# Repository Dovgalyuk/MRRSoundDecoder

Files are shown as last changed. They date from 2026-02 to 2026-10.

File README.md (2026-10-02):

# Maple RailRoad Sound Decoder

WiFi controller, sound decoder, and sound projects for model trains.

Project includes library for programming the sounds with set of state machines.

There are several ready-to-use sample sound projects.

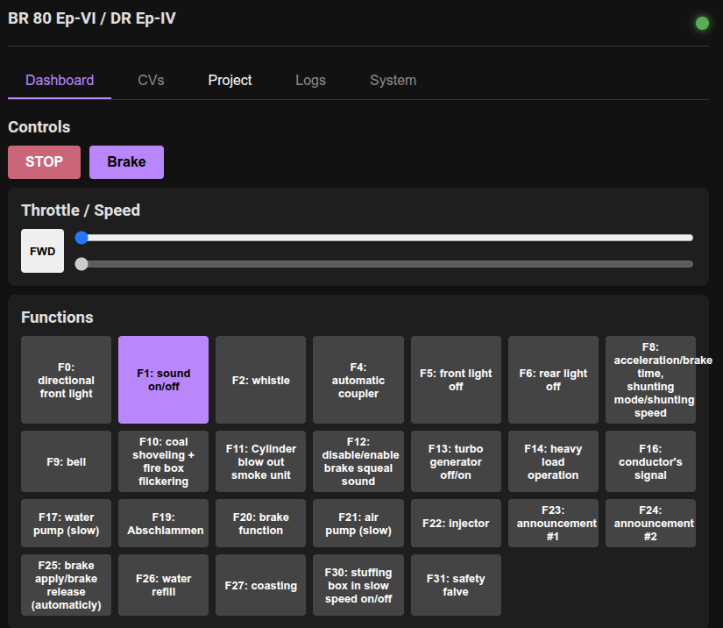
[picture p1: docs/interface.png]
Web interface for locomotive operation


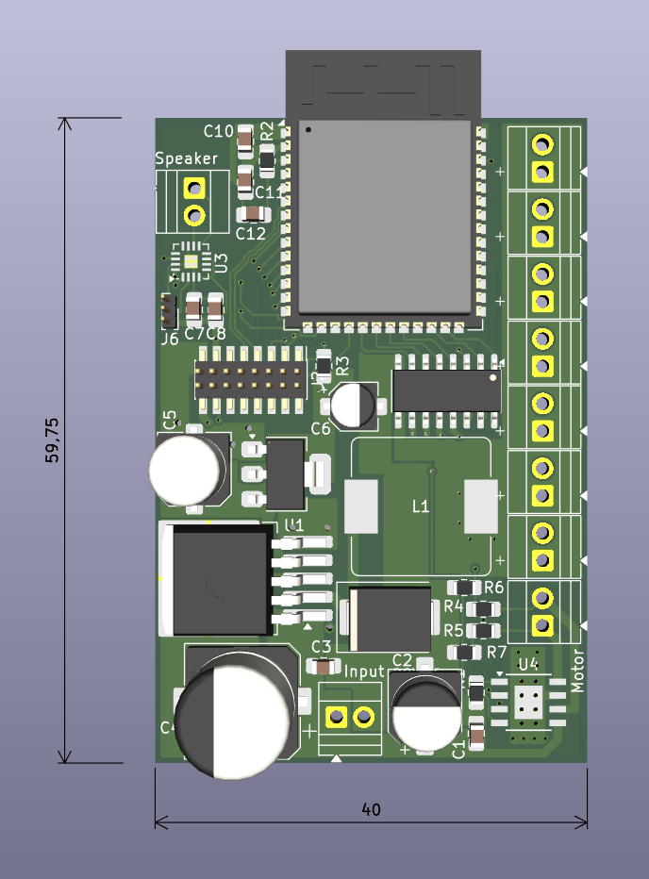
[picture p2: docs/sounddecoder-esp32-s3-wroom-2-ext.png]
Render of the PCB


# Project structure

* esp32 - firmwares for decoder and command station
* hardware - several versions of PCBs for manufacturing the decoder
* projects - ready-to-use sound projects for different locomotives
* compiler - compiler for the sound projects
* emulator - cab emulator for listening sounds with virtual locomotive control
* sample - dummy player which generates wav file by interpreting the sound project
* other directories include the source code of the firmware

# Bringing locomotive to life

* Get the hardware (order PCB, solder the components)
* Build firmware
  * Install ESP32 toolkit (esp idf)
  * Run esp32/decoder/build32M.sh (or other version)
* Upload esp32/decoder/build32M/esp32sounddecoder.bin into the ESP32 module
* Build selected sound project with compiler/compiler.py
* Upload built project through the web interface into the controller
* Install the controller into the locomotive

# Software features

Controller provides web interface that may be accessed through
WiFi (default address 192.168.4.1).

Sound module plays 8- or 16-bit sounds in 8 channels.

Output functions and sound schemes are programmed with
custom language. The scripts may include conditions,
loops, and finite state machines. These features
may be used for creating complex sound projects.

# Hardware

Controller is intended to be used with G-scale locomotives
with lithium batteries installed, but it may also be used
with track power (some power capacitors are probably needed).

Controller includes the following hardware components:
* ESP32 CPU with embedded WiFi module and flash memory
* Motor driver
* I2S audio power amplifier (MAX98357A)
* 7 programmable outputs
* BEMF for adjusting the motor speed (work in progress)

# Roadmap

* BEMF with new motor driver
* Support of logical input/outputs
* H0-compatible PCB

# Links

* Radio-controlled engines with sound
  - https://github.com/TheDIYGuy999/Rc_Engine_Sound_ESP32
* Cost effective DIY DCC Decoder for model railroad locomotives
  - https://github.com/gab-k/RP2040-Decoder
* NIMRS: open-source NIMRS-21Pin-Decoder, based on the ESP32-S3 microcontroller
  - https://github.com/CDFER/NIMRS-21Pin-Decoder
  - https://github.com/ProjectInitiative/NIMRS-Firmware

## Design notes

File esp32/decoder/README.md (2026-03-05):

# Prerequisites

Install ESP-IDF toolchain: https://docs.espressif.com/projects/esp-idf/en/stable/esp32/get-started/linux-macos-setup.html

Set environment variables: ```. {IDF PATH}/export.sh```

# Build

```
cd esp32

# choose target: esp32 or esp32s3
idf.py set-target esp32

idf.py build flash monitor
```

# Usage

Connect to WiFi train/12345678

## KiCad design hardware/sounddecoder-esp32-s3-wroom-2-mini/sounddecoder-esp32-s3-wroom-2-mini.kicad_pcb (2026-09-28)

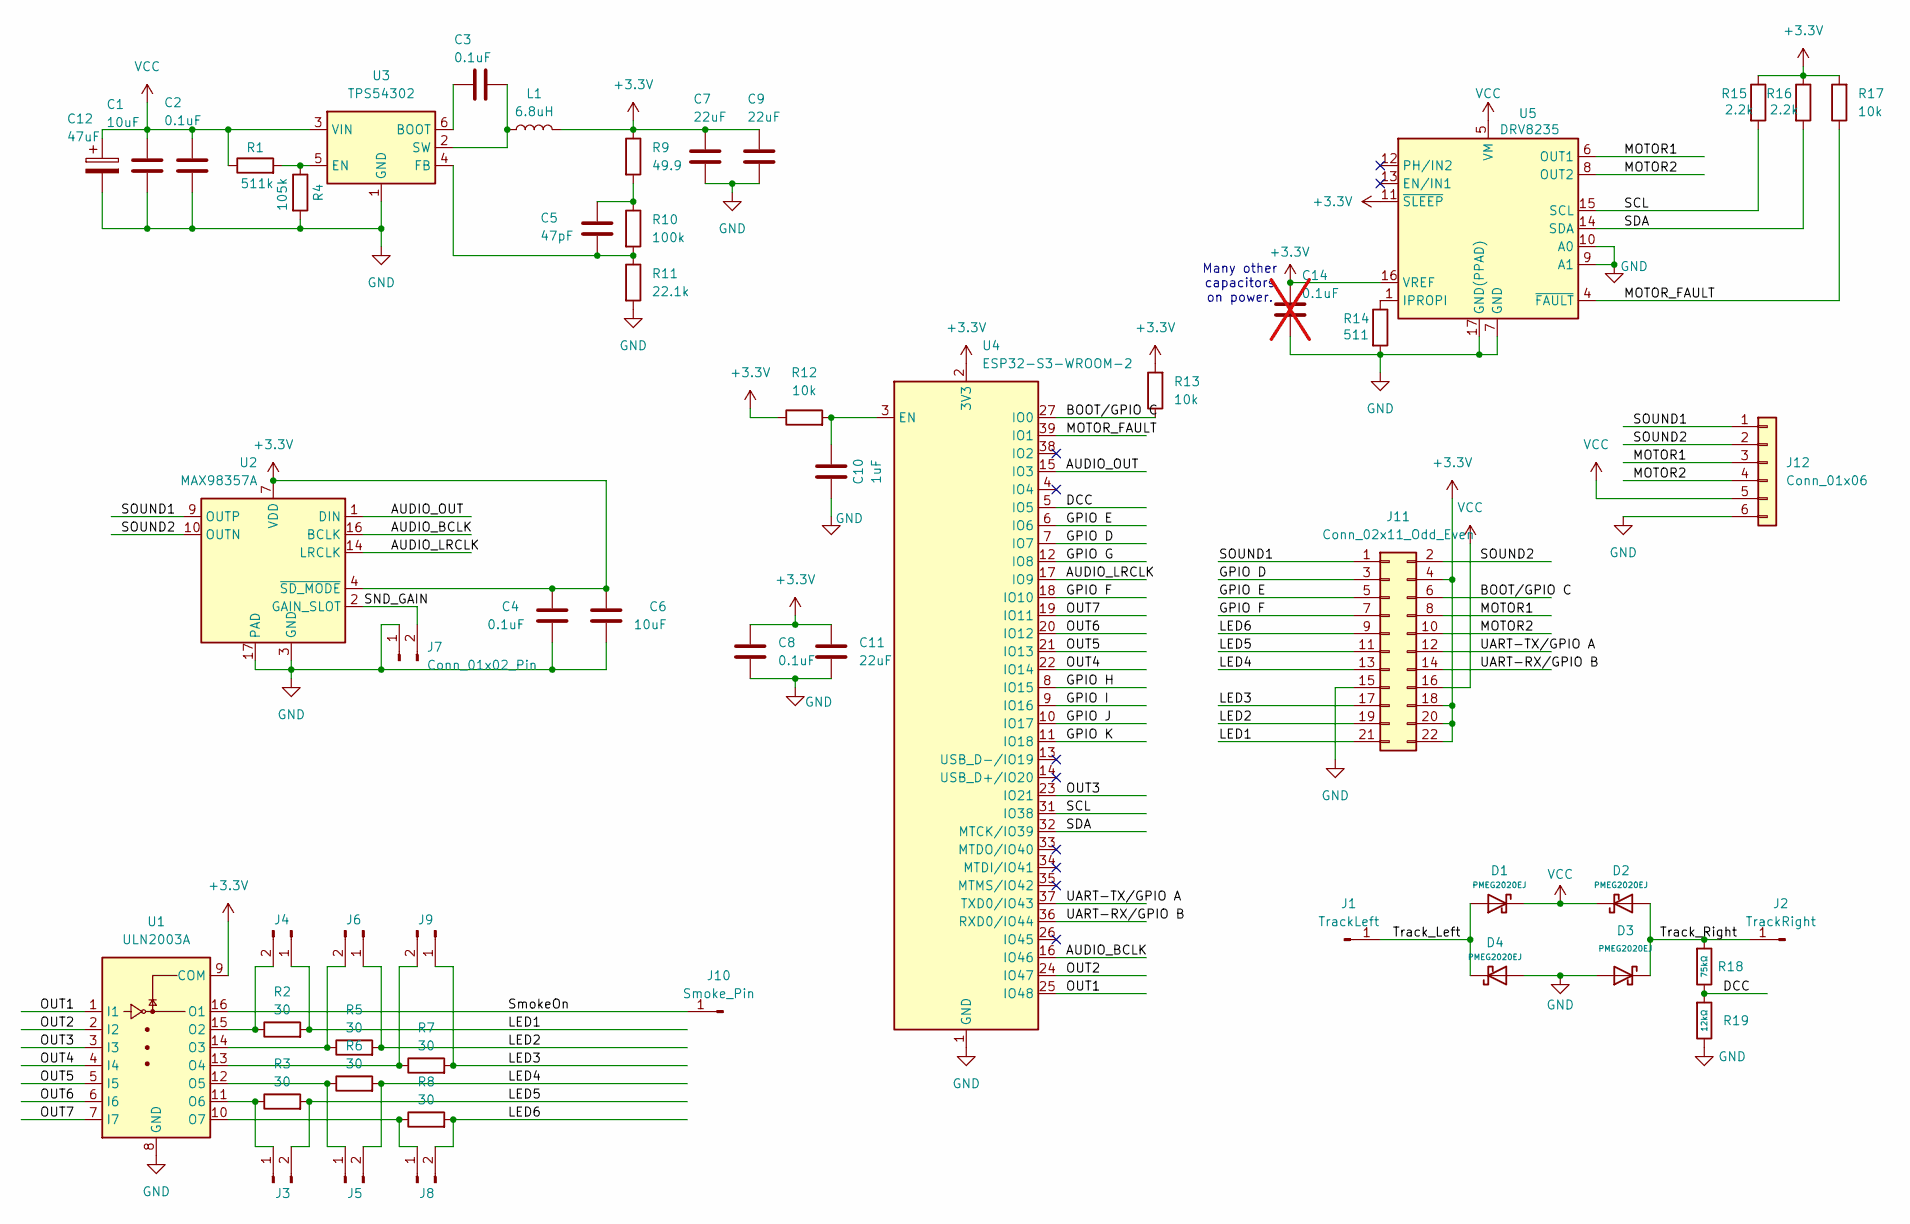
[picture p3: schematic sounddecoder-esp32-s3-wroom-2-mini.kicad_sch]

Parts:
C1, C6: 10uF; C_0603_1608Metric
C2, C3, C4, C8: 0.1uF; C_0603_1608Metric
C5: 47pF; C_0603_1608Metric
C7, C9, C11: 22uF; C_0603_1608Metric
C10: 1uF; C_0603_1608Metric
C12: 47uF; CP_Elec_6.3x5.4
C14: 0.1uF; C_0603_1608Metric; not fitted
D1, D2, D3, D4: PMEG2020EJ; D_SOD-323; Forward Voltage (Vf@If) 450mV@1.0A; Reverse Voltage (Vr) 20V; Part B5817WS; LCSC C7420329
J1: TrackLeft; TestPoint_THTPad_1.0x1.0mm_Drill0.5mm
J2: TrackRight; TestPoint_THTPad_1.0x1.0mm_Drill0.5mm
J3, J4, J5, J6, J7, J8, J9: Conn_01x02_Pin; SolderJumper-2_P1.3mm_Open_RoundedPad1.0x1.5mm
J10: Smoke_Pin; TestPoint_THTPad_1.0x1.0mm_Drill0.5mm
J11: Conn_02x11_Odd_Even; PinHeader_2x11_P2.00mm_Vertical
J12: Conn_01x06; PinHeader_1x06_P2.54mm_Vertical
L1: 6.8uH; L_Chilisin_BMRA00050530
R1: 511k; C_0603_1608Metric
R2, R3, R5, R6, R7, R8: 30; C_0603_1608Metric
R4: 105k; C_0603_1608Metric
R9: 49.9; C_0603_1608Metric
R10: 100k; C_0603_1608Metric
R11: 22.1k; C_0603_1608Metric
R12, R13, R17: 10k; C_0603_1608Metric
R14: 511; C_0603_1608Metric
R15, R16: 2.2k; C_0603_1608Metric
R18: 75kΩ; C_0603_1608Metric; Overload Voltage (Max) 50V; Tolerance ±1%; Part 0402WGF7502TCE; LCSC C25798
R19: 12kΩ; C_0603_1608Metric; Overload Voltage (Max) 50V; Tolerance ±1%; Part 0402WGF2002TCE; LCSC C25765
U1: ULN2003A; SO-16_3.9x9.9mm_P1.27mm
U2: MAX98357A; TQFN-16-1EP_3x3mm_P0.5mm_EP1.23x1.23mm
U3: TPS54302; SOT-23-6
U4: ESP32-S3-WROOM-2
U5: DRV8235; WQFN-16-1EP_3x3mm_P0.5mm_EP1.68x1.68mm_ThermalVias

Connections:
+3.3V: C4.1, C6.1, C7.1, C8.1, C9.1, C11.1, C14.1, J11.4, J11.18, J11.20, J11.22, L1.2, R9.1, R12.1, R13.2, R15.1, R16.1, R17.2, U1.9 (COM), U2.4 (~SD_MODE), U2.7 (VDD), U2.8 (VDD), U4.2 (3V3), U5.11 (~SLEEP), U5.16 (VREF)
/AUDIO_BCLK: U2.16 (BCLK), U4.16 (IO46)
/AUDIO_LRCLK: U2.14 (LRCLK), U4.17 (IO9)
/AUDIO_OUT: U2.1 (DIN), U4.15 (IO3)
/BOOT/GPIO C: J11.6, R13.1, U4.27 (IO0)
/DCC: R18.2, R19.1, U4.5 (IO5)
/GPIO D: J11.3, U4.7 (IO7)
/GPIO E: J11.5, U4.6 (IO6)
/GPIO F: J11.7, U4.18 (IO10)
/GPIO G: U4.12 (IO8)
/GPIO H: U4.8 (IO15)
/GPIO I: U4.9 (IO16)
/GPIO J: U4.10 (IO17)
/GPIO K: U4.11 (IO18)
/LED1: J4.1, J11.21, R2.2
/LED2: J6.1, J11.19, R5.2
/LED3: J9.1, J11.17, R7.2
/LED4: J5.2, J11.13, R6.2
/LED5: J3.2, J11.11, R3.2
/LED6: J8.2, J11.9, R8.2
/MOTOR1: J11.8, J12.3, U5.6 (OUT1)
/MOTOR2: J11.10, J12.4, U5.8 (OUT2)
/MOTOR_FAULT: R17.1, U4.39 (IO1), U5.4 (~FAULT)
/OUT1: U1.1 (I1), U4.25 (IO48)
/OUT2: U1.2 (I2), U4.24 (IO47)
/OUT3: U1.3 (I3), U4.23 (IO21)
/OUT4: U1.4 (I4), U4.22 (IO14)
/OUT5: U1.5 (I5), U4.21 (IO13)
/OUT6: U1.6 (I6), U4.20 (IO12)
/OUT7: U1.7 (I7), U4.19 (IO11)
/SCL: R15.2, U4.31 (IO38), U5.15 (SCL)
/SDA: R16.2, U4.32 (MTCK/IO39), U5.14 (SDA)
/SND_GAIN: J7.2, U2.2 (GAIN_SLOT)
/SOUND1: J11.1, J12.1, U2.9 (OUTP)
/SOUND2: J11.2, J12.2, U2.10 (OUTN)
/SmokeOn: J10.1, U1.16 (O1)
/Track_Left: D1.2, D4.1, J1.1
/Track_Right: D2.2, D3.1, J2.1, R18.1
/UART-RX/GPIO B: J11.14, U4.36 (RXD0/IO44)
/UART-TX/GPIO A: J11.12, U4.37 (TXD0/IO43)
GND: C1.2, C2.2, C4.2, C6.2, C7.2, C8.2, C9.2, C10.1, C11.2, C12.2, C14.2, D3.2, D4.2, J7.1, J11.15, J12.6, R4.2, R11.2, R14.2, R19.2, U1.8 (GND), U2.3 (GND), U2.11 (GND), U2.15 (GND), U2.17 (PAD), U3.1 (GND), U4.1 (GND), U4.40 (GND), U4.41 (GND), U5.7 (GND), U5.9 (A1), U5.10 (A0), U5.17 (GND(PPAD))
unnamed: C5.1, R9.2, R10.1
unnamed: J3.1, R3.1, U1.11 (O6)
unnamed: J4.2, R2.1, U1.15 (O2)
unnamed: J5.1, R6.1, U1.12 (O5)
unnamed: J6.2, R5.1, U1.14 (O3)
unnamed: J8.1, R8.1, U1.10 (O7)
unnamed: J9.2, R7.1, U1.13 (O4)
unnamed: C3.1, U3.6 (BOOT)
unnamed: R1.2, R4.1, U3.5 (EN)
unnamed: C5.2, R10.2, R11.1, U3.4 (FB)
unnamed: C3.2, L1.1, U3.2 (SW)
unnamed: C10.2, R12.2, U4.3 (EN)
unnamed: R14.1, U5.1 (IPROPI)
VCC: C1.1, C2.1, C12.1, D1.1, D2.1, J11.16, J12.5, R1.1, U3.3 (VIN), U5.5 (VM)

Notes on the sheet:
Many other capacitors on power.

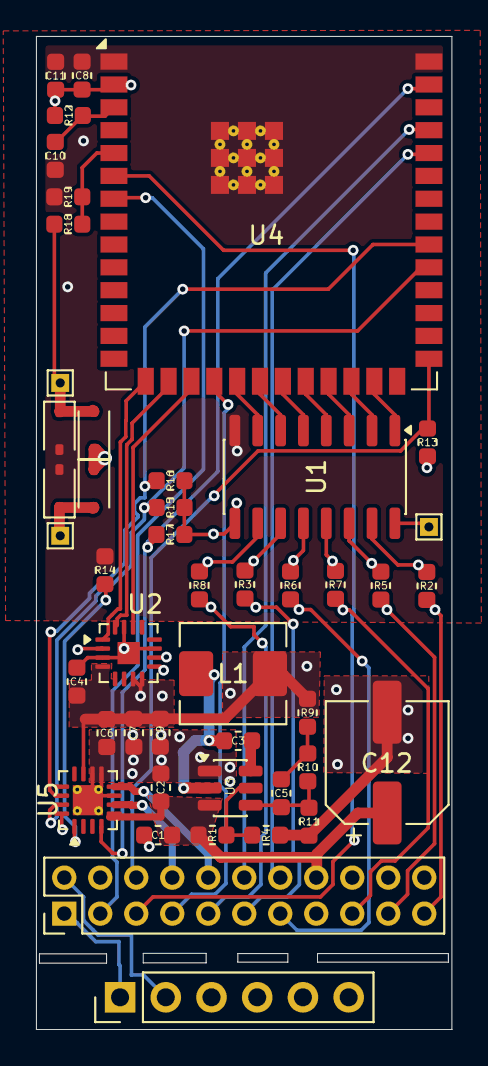
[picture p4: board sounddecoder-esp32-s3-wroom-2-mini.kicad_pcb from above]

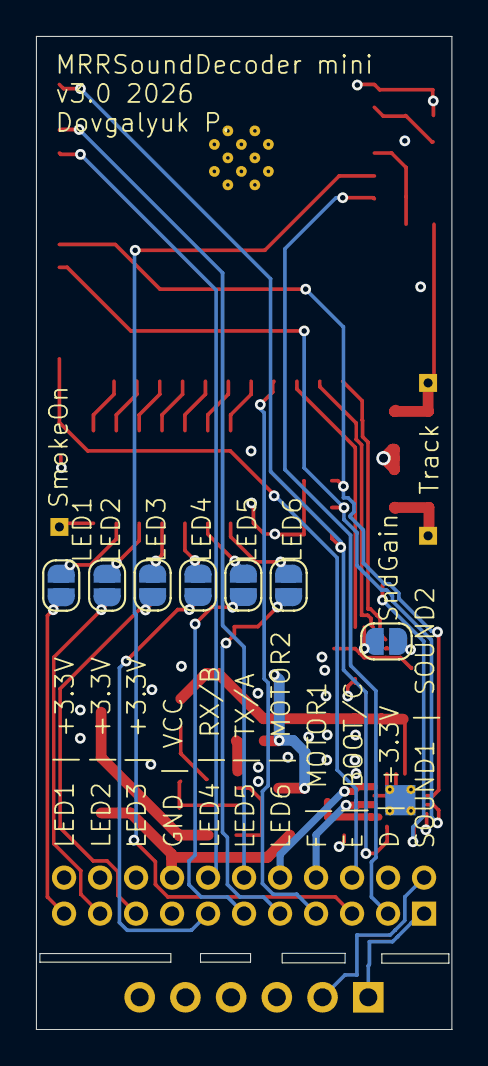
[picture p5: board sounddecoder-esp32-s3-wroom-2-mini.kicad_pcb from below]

Board: 4 copper layers, 23.1 x 55.2 mm, 53 parts (7 on the bottom side), 50 nets.

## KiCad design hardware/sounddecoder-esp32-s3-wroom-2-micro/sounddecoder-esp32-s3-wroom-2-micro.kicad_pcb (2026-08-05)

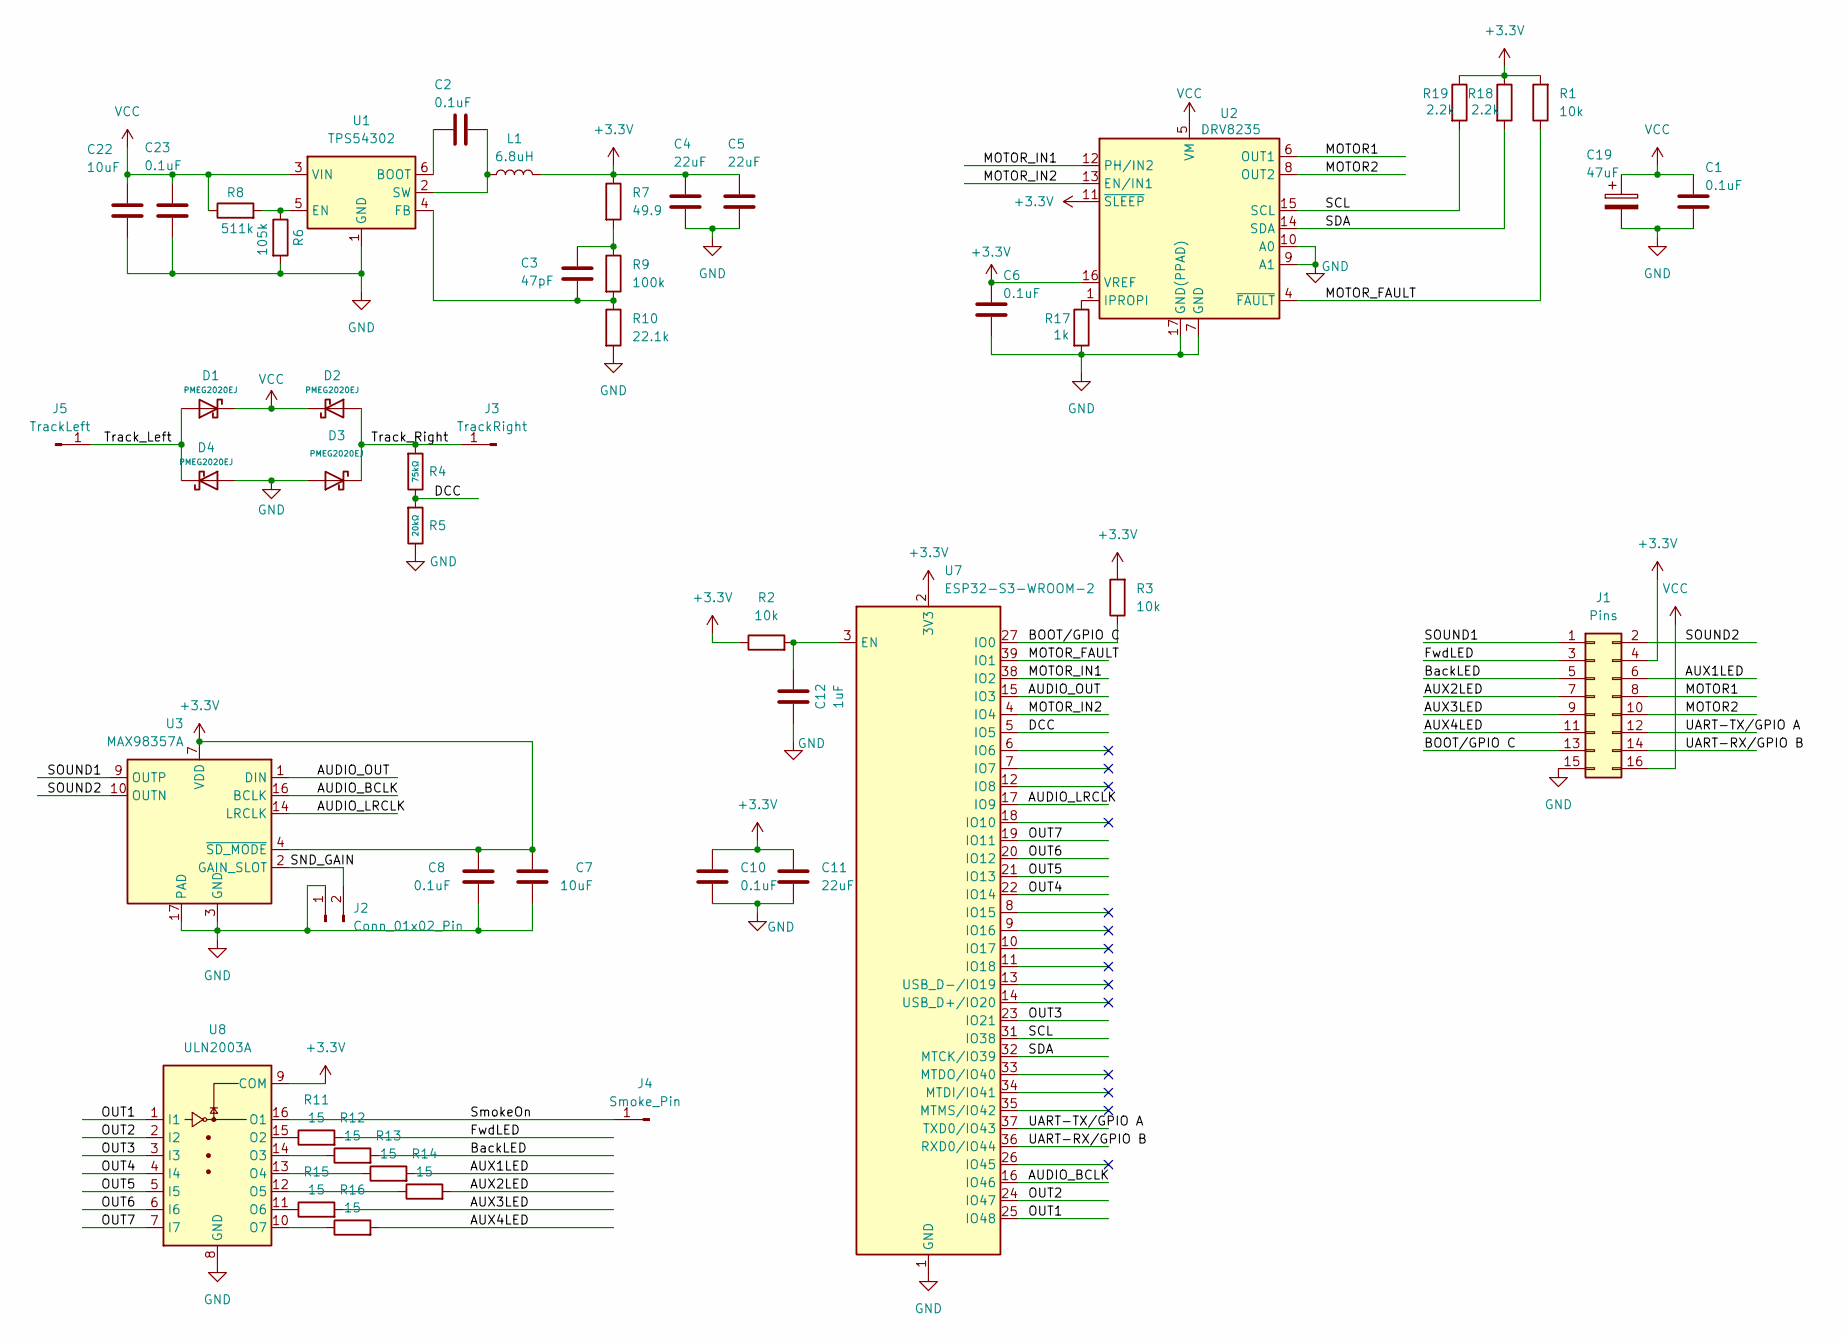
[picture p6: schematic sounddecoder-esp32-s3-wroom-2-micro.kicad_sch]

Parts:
C1, C2, C6, C8, C10, C23: 0.1uF; C_0603_1608Metric
C3: 47pF; C_0603_1608Metric
C4, C5, C11: 22uF; C_0603_1608Metric
C7, C22: 10uF; C_0603_1608Metric
C12: 1uF; C_0603_1608Metric
C19: 47uF; CP_Elec_6.3x5.4
D1, D2, D3, D4: PMEG2020EJ; D_SOD-323; Forward Voltage (Vf@If) 450mV@1.0A; Reverse Voltage (Vr) 20V; Part B5817WS; LCSC C7420329
J1: Pins; PinHeader_2x08_P2.00mm_Vertical
J2: Conn_01x02_Pin; SolderJumper-2_P1.3mm_Open_RoundedPad1.0x1.5mm
J3: TrackRight; TestPoint_THTPad_1.0x1.0mm_Drill0.5mm
J4: Smoke_Pin; TestPoint_THTPad_1.0x1.0mm_Drill0.5mm
J5: TrackLeft; TestPoint_THTPad_1.0x1.0mm_Drill0.5mm
L1: 6.8uH; L_Chilisin_BMRA00050530
R1, R2, R3: 10k; C_0603_1608Metric
R4: 75kΩ; C_0603_1608Metric; Overload Voltage (Max) 50V; Tolerance ±1%; Part 0402WGF7502TCE; LCSC C25798
R5: 20kΩ; C_0603_1608Metric; Overload Voltage (Max) 50V; Tolerance ±1%; Part 0402WGF2002TCE; LCSC C25765
R6: 105k; C_0603_1608Metric
R7: 49.9; C_0603_1608Metric
R8: 511k; C_0603_1608Metric
R9: 100k; C_0603_1608Metric
R10: 22.1k; C_0603_1608Metric
R11, R12, R13, R14, R15, R16: 15; C_0603_1608Metric
R17: 1k; C_0603_1608Metric
R18, R19: 2.2k; C_0603_1608Metric
U1: TPS54302; SOT-23-6
U2: DRV8235; WQFN-16-1EP_3x3mm_P0.5mm_EP1.68x1.68mm_ThermalVias
U3: MAX98357A; TQFN-16-1EP_3x3mm_P0.5mm_EP1.23x1.23mm
U7: ESP32-S3-WROOM-2
U8: ULN2003A; SO-16_3.9x9.9mm_P1.27mm

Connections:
+3.3V: C4.1, C5.1, C6.1, C7.1, C8.1, C10.1, C11.1, J1.4, L1.2, R1.2, R2.1, R3.2, R7.1, R18.1, R19.1, U2.11 (~SLEEP), U2.16 (VREF), U3.4 (~SD_MODE), U3.7 (VDD), U3.8 (VDD), U7.2 (3V3), U8.9 (COM)
/AUDIO_BCLK: U3.16 (BCLK), U7.16 (IO46)
/AUDIO_LRCLK: U3.14 (LRCLK), U7.17 (IO9)
/AUDIO_OUT: U3.1 (DIN), U7.15 (IO3)
/AUX1LED: J1.6, R13.2
/AUX2LED: J1.7, R14.2
/AUX3LED: J1.9, R15.2
/AUX4LED: J1.11, R16.2
/BOOT/GPIO C: J1.13, R3.1, U7.27 (IO0)
/BackLED: J1.5, R12.2
/DCC: R4.2, R5.1, U7.5 (IO5)
/FwdLED: J1.3, R11.2
/MOTOR1: J1.8, U2.6 (OUT1)
/MOTOR2: J1.10, U2.8 (OUT2)
/MOTOR_FAULT: R1.1, U2.4 (~FAULT), U7.39 (IO1)
/MOTOR_IN1: U2.12 (PH/IN2), U7.38 (IO2)
/MOTOR_IN2: U2.13 (EN/IN1), U7.4 (IO4)
/OUT1: U7.25 (IO48), U8.1 (I1)
/OUT2: U7.24 (IO47), U8.2 (I2)
/OUT3: U7.23 (IO21), U8.3 (I3)
/OUT4: U7.22 (IO14), U8.4 (I4)
/OUT5: U7.21 (IO13), U8.5 (I5)
/OUT6: U7.20 (IO12), U8.6 (I6)
/OUT7: U7.19 (IO11), U8.7 (I7)
/SCL: R19.2, U2.15 (SCL), U7.31 (IO38)
/SDA: R18.2, U2.14 (SDA), U7.32 (MTCK/IO39)
/SND_GAIN: J2.2, U3.2 (GAIN_SLOT)
/SOUND1: J1.1, U3.9 (OUTP)
/SOUND2: J1.2, U3.10 (OUTN)
/SmokeOn: J4.1, U8.16 (O1)
/Track_Left: D1.2, D4.1, J5.1
/Track_Right: D2.2, D3.1, J3.1, R4.1
/UART-RX/GPIO B: J1.14, U7.36 (RXD0/IO44)
/UART-TX/GPIO A: J1.12, U7.37 (TXD0/IO43)
GND: C1.2, C4.2, C5.2, C6.2, C7.2, C8.2, C10.2, C11.2, C12.1, C19.2, C22.2, C23.2, D3.2, D4.2, J1.15, J2.1, R5.2, R6.2, R10.2, R17.2, U1.1 (GND), U2.7 (GND), U2.9 (A1), U2.10 (A0), U2.17 (GND(PPAD)), U3.3 (GND), U3.11 (GND), U3.15 (GND), U3.17 (PAD), U7.1 (GND), U7.40 (GND), U7.41 (GND), U8.8 (GND)
unnamed: C3.1, R7.2, R9.1
unnamed: C2.1, U1.6 (BOOT)
unnamed: R6.1, R8.2, U1.5 (EN)
unnamed: C3.2, R9.2, R10.1, U1.4 (FB)
unnamed: C2.2, L1.1, U1.2 (SW)
unnamed: R17.1, U2.1 (IPROPI)
unnamed: C12.2, R2.2, U7.3 (EN)
unnamed: R11.1, U8.15 (O2)
unnamed: R12.1, U8.14 (O3)
unnamed: R13.1, U8.13 (O4)
unnamed: R14.1, U8.12 (O5)
unnamed: R15.1, U8.11 (O6)
unnamed: R16.1, U8.10 (O7)
VCC: C1.1, C19.1, C22.1, C23.1, D1.1, D2.1, J1.16, R8.1, U1.3 (VIN), U2.5 (VM)

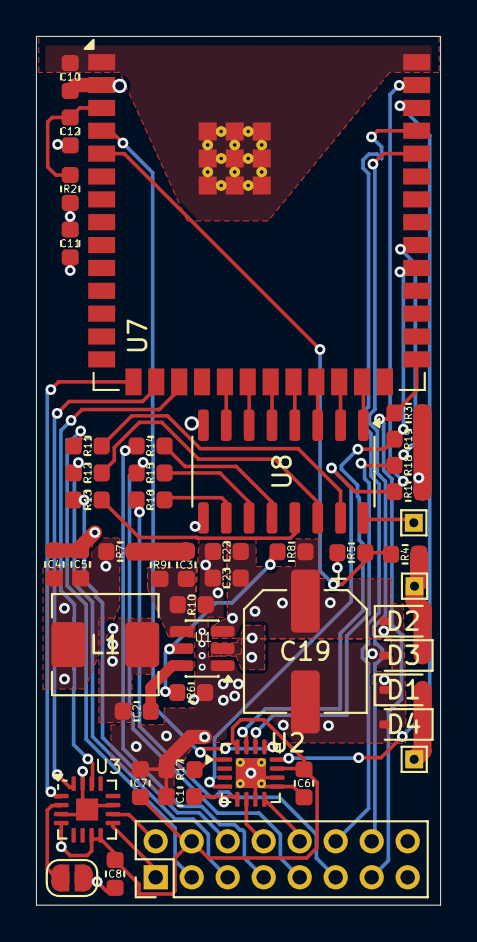
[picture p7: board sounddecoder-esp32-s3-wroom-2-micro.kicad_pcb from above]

Board: 4 copper layers, 22.5 x 48.3 mm, 48 parts (0 on the bottom side), 49 nets.

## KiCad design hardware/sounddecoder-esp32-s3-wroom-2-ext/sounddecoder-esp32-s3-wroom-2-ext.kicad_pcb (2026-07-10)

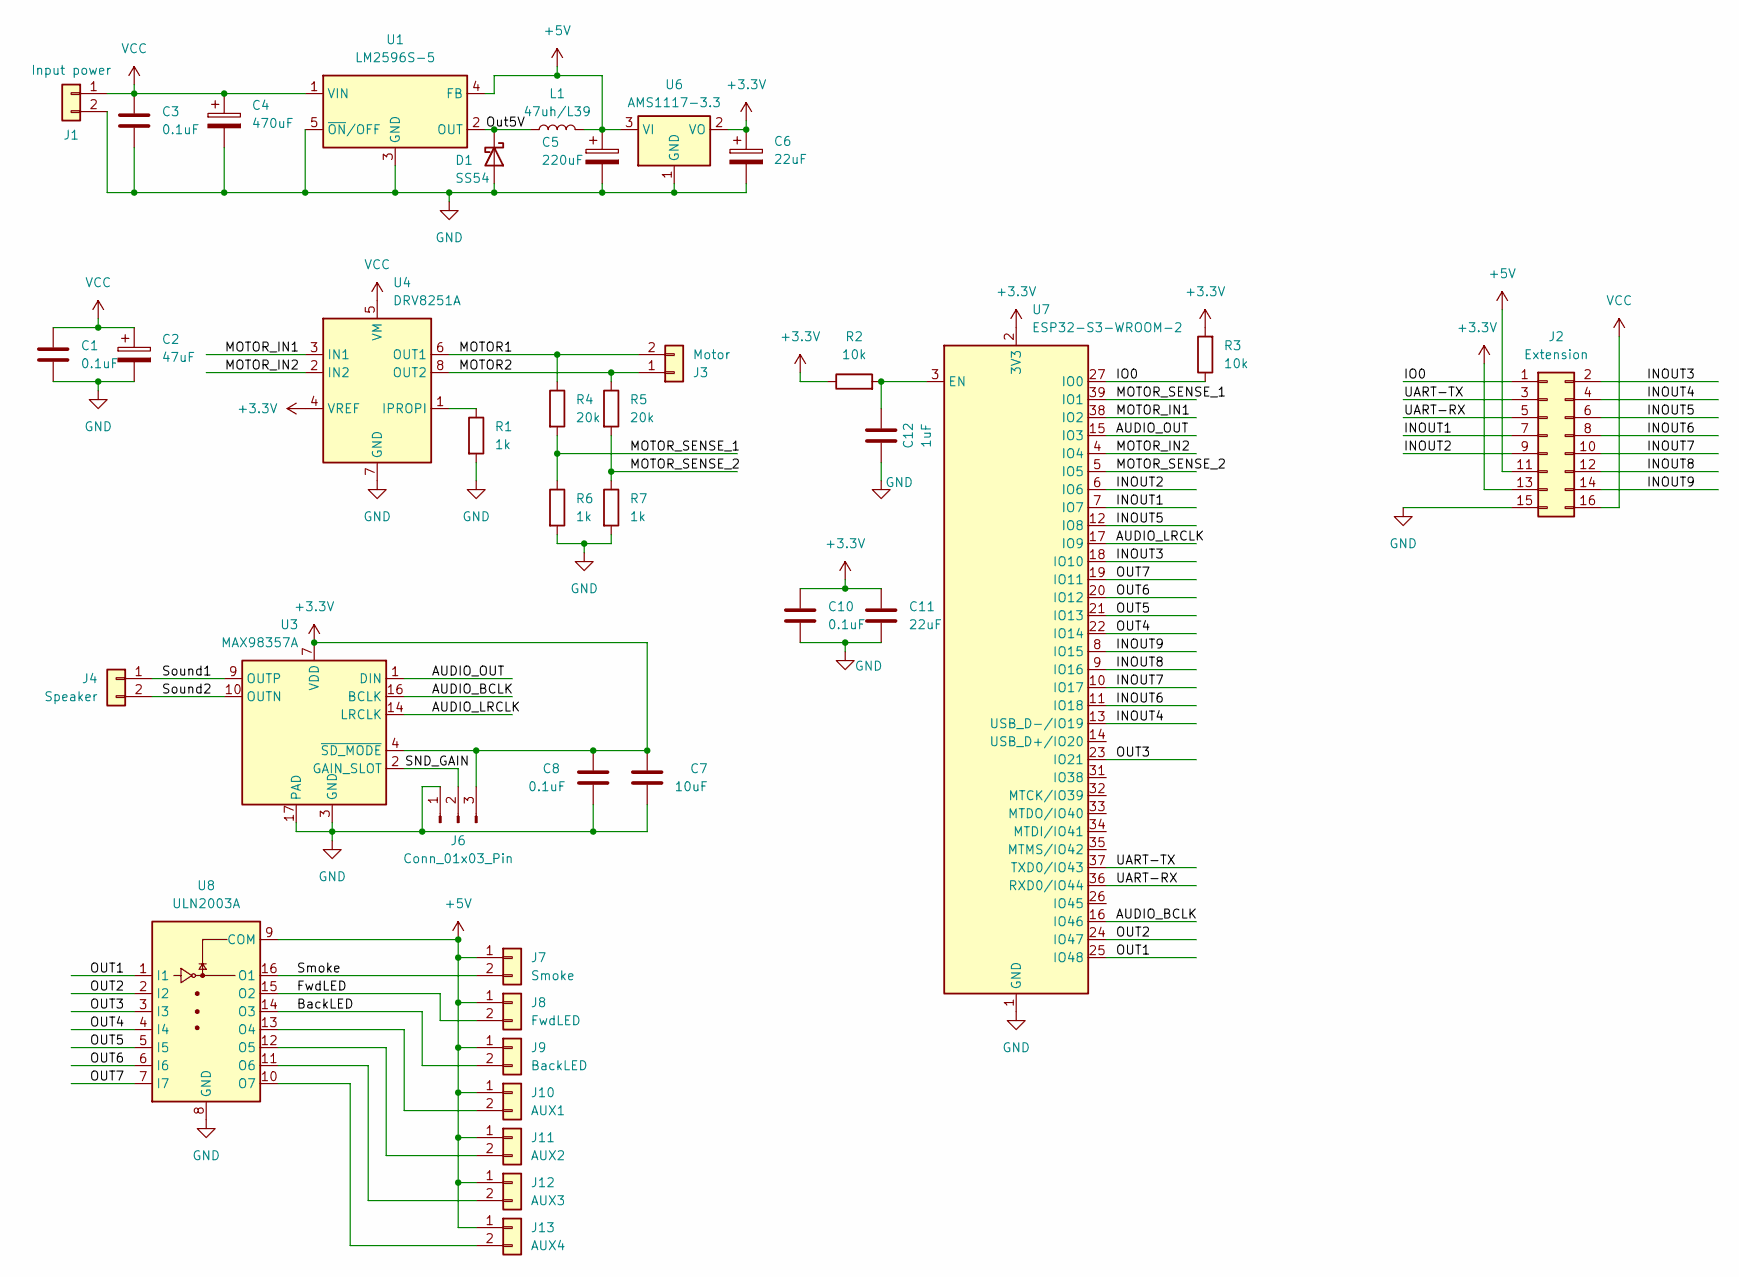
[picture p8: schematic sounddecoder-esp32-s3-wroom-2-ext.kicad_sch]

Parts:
C1, C3, C8, C10: 0.1uF; C_0805_2012Metric_Pad1.18x1.45mm_HandSolder
C2: 47uF; CP_Elec_6.3x5.4
C4: 470uF; CP_Elec_10x10.5
C5: 220uF; C_Elec_6.3x7.7
C6: 22uF; CP_Elec_4x5.4
C7: 10uF; C_0805_2012Metric_Pad1.18x1.45mm_HandSolder
C11: 22uF; C_0805_2012Metric_Pad1.18x1.45mm_HandSolder
C12: 1uF; C_0805_2012Metric_Pad1.18x1.45mm_HandSolder
D1: SS54; D_SMC
J1: Input power; TerminalBlock_Xinya_XY308-2.54-2P_1x02_P2.54mm_Horizontal
J2: Extension; PinHeader_2x08_P1.27mm_Vertical_SMD
J3: Motor; TerminalBlock_Xinya_XY308-2.54-2P_1x02_P2.54mm_Horizontal
J4: Speaker; TerminalBlock_Xinya_XY308-2.54-2P_1x02_P2.54mm_Horizontal
J6: Conn_01x03_Pin; PinHeader_1x03_P1.00mm_Vertical
J7: Smoke; TerminalBlock_Xinya_XY308-2.54-2P_1x02_P2.54mm_Horizontal
J8: FwdLED; TerminalBlock_Xinya_XY308-2.54-2P_1x02_P2.54mm_Horizontal
J9: BackLED; TerminalBlock_Xinya_XY308-2.54-2P_1x02_P2.54mm_Horizontal
J10: AUX1; TerminalBlock_Xinya_XY308-2.54-2P_1x02_P2.54mm_Horizontal
J11: AUX2; TerminalBlock_Xinya_XY308-2.54-2P_1x02_P2.54mm_Horizontal
J12: AUX3; TerminalBlock_Xinya_XY308-2.54-2P_1x02_P2.54mm_Horizontal
J13: AUX4; TerminalBlock_Xinya_XY308-2.54-2P_1x02_P2.54mm_Horizontal
L1: 47uh/L39; L_Bourns_SRP1245A
R1, R6, R7: 1k; R_0805_2012Metric_Pad1.20x1.40mm_HandSolder
R2, R3: 10k; R_0805_2012Metric_Pad1.20x1.40mm_HandSolder
R4, R5: 20k; R_0805_2012Metric_Pad1.20x1.40mm_HandSolder
U1: LM2596S-5; TO-263-5_TabPin3
U3: MAX98357A; TQFN-16-1EP_3x3mm_P0.5mm_EP1.23x1.23mm
U4: DRV8251A; Texas_HSOP-8-1EP_3.9x4.9mm_P1.27mm_ThermalVias
U6: AMS1117-3.3; SOT-223-3_TabPin2
U7: ESP32-S3-WROOM-2
U8: ULN2003A; SO-16_3.9x9.9mm_P1.27mm

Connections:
+3.3V: C6.1, C7.1, C8.1, C10.1, C11.1, J2.13, J6.3, R2.1, R3.2, U3.4 (~SD_MODE), U3.7 (VDD), U3.8 (VDD), U4.4 (VREF), U6.2 (VO), U7.2 (3V3)
+5V: C5.1, J2.11, J7.1, J8.1, J9.1, J10.1, J11.1, J12.1, J13.1, L1.2, U1.4 (FB), U6.3 (VI), U8.9 (COM)
/AUDIO_BCLK: U3.16 (BCLK), U7.16 (IO46)
/AUDIO_LRCLK: U3.14 (LRCLK), U7.17 (IO9)
/AUDIO_OUT: U3.1 (DIN), U7.15 (IO3)
/BackLED: J9.2, U8.14 (O3)
/FwdLED: J8.2, U8.15 (O2)
/INOUT1: J2.7, U7.7 (IO7)
/INOUT2: J2.9, U7.6 (IO6)
/INOUT3: J2.2, U7.18 (IO10)
/INOUT4: J2.4, U7.13 (USB_D-/IO19)
/INOUT5: J2.6, U7.12 (IO8)
/INOUT6: J2.8, U7.11 (IO18)
/INOUT7: J2.10, U7.10 (IO17)
/INOUT8: J2.12, U7.9 (IO16)
/INOUT9: J2.14, U7.8 (IO15)
/IO0: J2.1, R3.1, U7.27 (IO0)
/MOTOR1: J3.2, R4.1, U4.6 (OUT1)
/MOTOR2: J3.1, R5.1, U4.8 (OUT2)
/MOTOR_IN1: U4.3 (IN1), U7.38 (IO2)
/MOTOR_IN2: U4.2 (IN2), U7.4 (IO4)
/MOTOR_SENSE_1: R4.2, R6.1, U7.39 (IO1)
/MOTOR_SENSE_2: R5.2, R7.1, U7.5 (IO5)
/OUT1: U7.25 (IO48), U8.1 (I1)
/OUT2: U7.24 (IO47), U8.2 (I2)
/OUT3: U7.23 (IO21), U8.3 (I3)
/OUT4: U7.22 (IO14), U8.4 (I4)
/OUT5: U7.21 (IO13), U8.5 (I5)
/OUT6: U7.20 (IO12), U8.6 (I6)
/OUT7: U7.19 (IO11), U8.7 (I7)
/Out5V: D1.1 (K), L1.1, U1.2 (OUT)
/SND_GAIN: J6.2, U3.2 (GAIN_SLOT)
/Smoke: J7.2, U8.16 (O1)
/Sound1: J4.1, U3.9 (OUTP)
/Sound2: J4.2, U3.10 (OUTN)
/UART-RX: J2.5, U7.36 (RXD0/IO44)
/UART-TX: J2.3, U7.37 (TXD0/IO43)
GND: C1.2, C2.2, C3.2, C4.2, C5.2, C6.2, C7.2, C8.2, C10.2, C11.2, C12.1, D1.2 (A), J1.2, J2.15, J6.1, R1.2, R6.2, R7.2, U1.3 (GND), U1.5 (~ON/OFF), U3.3 (GND), U3.11 (GND), U3.15 (GND), U3.17 (PAD), U4.7 (GND), U4.9 (GND), U6.1 (GND), U7.1 (GND), U7.40 (GND), U7.41 (GND), U8.8 (GND)
unnamed: J10.2, U8.13 (O4)
unnamed: J11.2, U8.12 (O5)
unnamed: J12.2, U8.11 (O6)
unnamed: J13.2, U8.10 (O7)
unnamed: R1.1, U4.1 (IPROPI)
unnamed: C12.2, R2.2, U7.3 (EN)
VCC: C1.1, C2.1, C3.1, C4.1, J1.1, J2.16, U1.1 (VIN), U4.5 (VM)

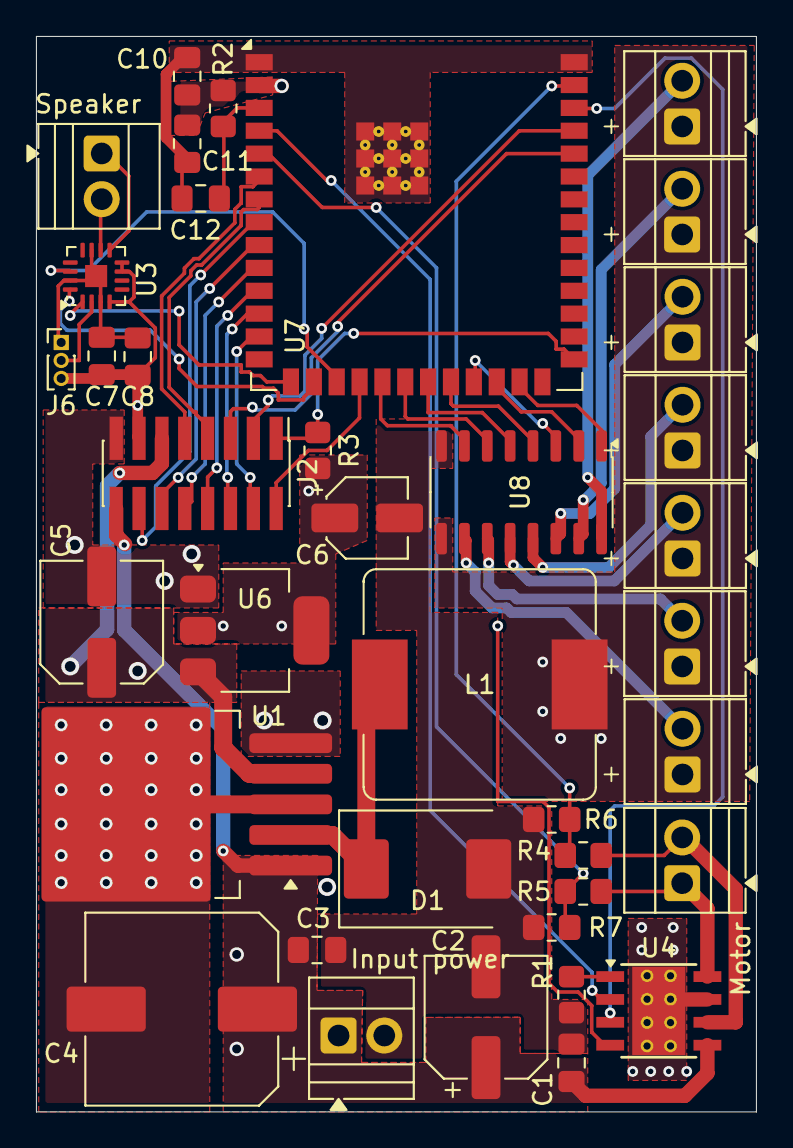
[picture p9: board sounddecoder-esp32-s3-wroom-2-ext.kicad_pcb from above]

Board: 4 copper layers, 40.0 x 59.8 mm, 38 parts (0 on the bottom side), 45 nets.

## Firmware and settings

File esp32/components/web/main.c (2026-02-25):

/* Async Request Handlers HTTP Server Example

   This example code is in the Public Domain (or CC0 licensed, at your option.)

   Unless required by applicable law or agreed to in writing, this
   software is distributed on an "AS IS" BASIS, WITHOUT WARRANTIES OR
   CONDITIONS OF ANY KIND, either express or implied.
*/
#include "freertos/FreeRTOS.h"
#include "freertos/semphr.h"
#include <esp_event.h>
#include <esp_log.h>
#include <esp_system.h>
#include <sys/param.h>
#include <esp_http_server.h>

/* An example that demonstrates multiple
   long running http requests running in parallel.

   In this example, multiple long http request can run at
   the same time. (uri: /long)

   While these long requests are running, the server can still
   respond to other incoming synchronous requests. (uri: /quick)
 */

#define ASYNC_WORKER_TASK_PRIORITY      5

static const char *TAG = "http";

// Async requests are queued here while they wait to
// be processed by the workers
static QueueHandle_t request_queue;

// Track the number of free workers at any given time
static SemaphoreHandle_t worker_ready_count;

// Each worker has its own thread
static TaskHandle_t worker_handles[CONFIG_HTTP_MAX_ASYNC_REQUESTS];

typedef esp_err_t (*httpd_req_handler_t)(httpd_req_t *req);

typedef struct {
    httpd_req_t* req;
    httpd_req_handler_t handler;
} httpd_async_req_t;

// queue an HTTP req to the worker queue
static esp_err_t queue_request(httpd_req_t *req, httpd_req_handler_t handler)
{
    // must create a copy of the request that we own
    httpd_req_t* copy = NULL;
    esp_err_t err = httpd_req_async_handler_begin(req, &copy);
    if (err != ESP_OK) {
        return err;
    }

    httpd_async_req_t async_req = {
        .req = copy,
        .handler = handler,
    };

    // How should we handle resource exhaustion?
    // In this example, we immediately respond with an
    // http error if no workers are available.
    int ticks = 0;

    // counting semaphore: if success, we know 1 or
    // more asyncReqTaskWorkers are available.
    if (xSemaphoreTake(worker_ready_count, ticks) == false) {
        ESP_LOGE(TAG, "No workers are available");
        httpd_req_async_handler_complete(copy); // cleanup
        return ESP_FAIL;
    }

    // Since worker_ready_count > 0 the queue should already have space.
    // But lets wait up to 100ms just to be safe.
    if (xQueueSend(request_queue, &async_req, pdMS_TO_TICKS(100)) == false) {
        ESP_LOGE(TAG, "worker queue is full");
        httpd_req_async_handler_complete(copy); // cleanup
        return ESP_FAIL;
    }

    return ESP_OK;
}

/* handle long request (on async thread) */
static esp_err_t long_async(httpd_req_t *req)
{
    char*  buf;
    size_t buf_len;

    /* Get URI */
    ESP_LOGI(TAG, "Request URI: %s", req->uri);

    /* Get header value string length and allocate memory for length + 1,
     * extra byte for null termination */
    buf_len = httpd_req_get_hdr_value_len(req, "Host") + 1;
    if (buf_len > 1) {
        buf = malloc(buf_len);
        if (buf == NULL) {
            ESP_LOGE(TAG, "Failed to allocate memory for headers");
            return ESP_FAIL;
        }
        /* Copy null terminated value string into buffer */
        if (httpd_req_get_hdr_value_str(req, "Host", buf, buf_len) == ESP_OK) {
            ESP_LOGI(TAG, "Found header => Host: %s", buf);
        }
        free(buf);
    }
    /* Get query string length and allocate memory for length + 1,
     * extra byte for null termination */
    buf_len = httpd_req_get_url_query_len(req) + 1;
    if (buf_len > 1) {
        buf = malloc(buf_len);
        if (buf == NULL) {
            ESP_LOGE(TAG, "Failed to allocate memory for query string");
            return ESP_FAIL;
        }
        /* Copy null terminated query string into buffer */
        if (httpd_req_get_url_query_str(req, buf, buf_len) == ESP_OK) {
            ESP_LOGI(TAG, "Found query string => %s", buf);
        }
        free(buf);
    }

    // track the number of long requests
    static uint8_t req_count = 0;
    req_count++;

    // send a request count
    char s[100];
    snprintf(s, sizeof(s), "<div>req: %u</div>\n", req_count);
    esp_err_t err = httpd_resp_sendstr_chunk(req, s);
    if (err != ESP_OK) {
        ESP_LOGE(TAG, "Failed to send string chunk: %s", esp_err_to_name(err));
        return err;
    }

    // then every second, send a "tick"
    for (int i = 0; i < 60; i++) {

        // This delay makes this a "long running task".
        // In a real application, this may be a long calculation,
        // or some IO dependent code for instance.
        vTaskDelay(pdMS_TO_TICKS(1000));

        // send a tick
        snprintf(s, sizeof(s), "<div>%u</div>\n", i);
        err = httpd_resp_sendstr_chunk(req, s);
        if (err != ESP_OK) {
            ESP_LOGE(TAG, "Failed to send string chunk: %s", esp_err_to_name(err));
            return err;
        }
    }

    // send "complete"
    err = httpd_resp_sendstr_chunk(req, NULL);
    if (err != ESP_OK) {
        ESP_LOGE(TAG, "Failed to send string chunk: %s", esp_err_to_name(err));
        return err;
    }

    return ESP_OK;
}

// each worker thread loops forever, processing requests
static void worker_task(void *p)
{
    ESP_LOGI(TAG, "starting async req task worker");

    while (true) {

        // counting semaphore - this signals that a worker
        // is ready to accept work
        xSemaphoreGive(worker_ready_count);

        // wait for a request
        httpd_async_req_t async_req;
        if (xQueueReceive(request_queue, &async_req, portMAX_DELAY)) {

            ESP_LOGI(TAG, "invoking %s", async_req.req->uri);

            // call the handler
            async_req.handler(async_req.req);

            // Inform the server that it can purge the socket used for
            // this request, if needed.
            if (httpd_req_async_handler_complete(async_req.req) != ESP_OK) {
                ESP_LOGE(TAG, "failed to complete async req");
            }
        }
    }

    ESP_LOGW(TAG, "worker stopped");
    vTaskDelete(NULL);
}

// start worker threads
static void start_workers(void)
{

    // counting semaphore keeps track of available workers
    worker_ready_count = xSemaphoreCreateCounting(
        CONFIG_HTTP_MAX_ASYNC_REQUESTS,  // Max Count
        0); // Initial Count
    if (worker_ready_count == NULL) {
        ESP_LOGE(TAG, "Failed to create workers counting Semaphore");
        return;
    }

    // create queue
    request_queue = xQueueCreate(1, sizeof(httpd_async_req_t));
    if (request_queue == NULL){
        ESP_LOGE(TAG, "Failed to create request_queue");
        vSemaphoreDelete(worker_ready_count);
        return;
    }

    // start worker tasks
    for (int i = 0; i < CONFIG_HTTP_MAX_ASYNC_REQUESTS; i++) {

        bool success = xTaskCreatePinnedToCore(worker_task, "async_req_worker",
                                    CONFIG_HTTP_ASYNC_WORKER_TASK_STACK_SIZE, // stack size
                                    (void *)0, // argument
                                    ASYNC_WORKER_TASK_PRIORITY, // priority
                                    &worker_handles[i], 0);

        if (!success) {
            ESP_LOGE(TAG, "Failed to start asyncReqWorker");
            continue;
        }
    }
}

/* adds /long request to the request queue */
static esp_err_t long_handler(httpd_req_t *req)
{
    ESP_LOGI(TAG, "uri: /long");

    // add to the async request queue
    if (queue_request(req, long_async) == ESP_OK) {
        return ESP_OK;
    } else {
        httpd_resp_set_status(req, "503 Busy");
        httpd_resp_sendstr(req, "<div> no workers available. server busy.</div>");
        return ESP_OK;
    }
}

/* A quick HTTP GET handler, which does not
   use any asynchronous features */
static esp_err_t quick_handler(httpd_req_t *req)
{
    ESP_LOGI(TAG, "uri: /quick");
    char s[100];
    snprintf(s, sizeof(s), "random: %u\n", rand());
    httpd_resp_sendstr(req, s);
    return ESP_OK;
}

static esp_err_t index_handler(httpd_req_t *req)
{
    ESP_LOGI(TAG, "uri: /");
    const char* html = "<div><a href=\"/long\">long</a></div>"
        "<div><a href=\"/quick\">quick</a></div>"
        "<div><a href=\"/myquick\">myquick</a></div>";
    httpd_resp_sendstr(req, html);
    return ESP_OK;
}

static httpd_handle_t start_webserver(void)
{
    httpd_handle_t server = NULL;
    httpd_config_t config = HTTPD_DEFAULT_CONFIG();
    config.lru_purge_enable = true;

    // It is advisable that httpd_config_t->max_open_sockets > MAX_ASYNC_REQUESTS
    // Why? This leaves at least one socket still available to handle
    // quick synchronous requests. Otherwise, all the sockets will
    // get taken by the long async handlers, and your server will no
    // longer be responsive.
    config.max_open_sockets = CONFIG_HTTP_MAX_ASYNC_REQUESTS + 1;

    // Start the httpd server
    ESP_LOGI(TAG, "Starting server on port: '%d'", config.server_port);
    if (httpd_start(&server, &config) != ESP_OK) {
        ESP_LOGI(TAG, "Error starting server!");
        return NULL;
    }

    const httpd_uri_t index_uri = {
        .uri       = "/",
        .method    = HTTP_GET,
        .handler   = index_handler,
    };

    const httpd_uri_t long_uri = {
        .uri       = "/long",
        .method    = HTTP_GET,
        .handler   = long_handler,
    };

    const httpd_uri_t quick_uri = {
        .uri       = "/quick",
        .method    = HTTP_GET,
        .handler   = quick_handler,
    };

    const httpd_uri_t quick_uri1 = {
        .uri       = "/myquick",
        .method    = HTTP_GET,
        .handler   = quick_handler,
    };

    // Set URI handlers
    ESP_LOGI(TAG, "Registering URI handlers");
    httpd_register_uri_handler(server, &index_uri);
    httpd_register_uri_handler(server, &long_uri);
    httpd_register_uri_handler(server, &quick_uri);
    httpd_register_uri_handler(server, &quick_uri1);

    return server;
}

void web_init(void)
{
    // static httpd_handle_t server = NULL;

    // start workers
    start_workers();

    /* Start the server for the first time */
    /*server = */start_webserver();
}

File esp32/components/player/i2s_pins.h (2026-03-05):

#pragma once

#include "sdkconfig.h"

#ifdef __cplusplus
extern "C" {
#endif

#if CONFIG_IDF_TARGET_ESP32
#define I2S_BCLK_IO1        GPIO_NUM_26     // I2S bit clock io number
#define I2S_WS_IO1          GPIO_NUM_27     // I2S word select io number
#define I2S_DOUT_IO1        GPIO_NUM_25     // I2S data out io number

#elif CONFIG_IDF_TARGET_ESP32S3
#define I2S_BCLK_IO1        GPIO_NUM_36     // I2S bit clock io number
#define I2S_WS_IO1          GPIO_NUM_37     // I2S word select io number
#define I2S_DOUT_IO1        GPIO_NUM_35     // I2S data out io number

#else
#error Define pins for player
#endif

#ifdef __cplusplus
}
#endif

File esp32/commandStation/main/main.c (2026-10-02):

#include "freertos/FreeRTOS.h"
#include "freertos/task.h"
#include "esp_err.h"
#include "esp_memory_utils.h"
#include "esp_chip_info.h"
#include "esp_flash.h"
#include "lvgl.h"
#include "bsp/esp-bsp.h"
#include "bsp/display.h"

#include "logger.h"

#define MAX_TRAINS 5

static lv_obj_t *train_tabs[MAX_TRAINS];
static lv_obj_t *train_names[MAX_TRAINS];

void logger_init(lv_obj_t *tab);
void wifi_init(void);

void app_main(void)
{
    lv_display_t *disp = bsp_display_start();
    bsp_display_backlight_on();

    bsp_display_lock(0);

    lv_obj_t * screen = lv_screen_active();
    // lv_obj_set_style_bg_color(screen, lv_color_hex(0x003a57), 0);
    // lv_obj_set_style_text_color(screen, lv_color_hex(0xffffff), 0);

    lv_obj_t *tabview = lv_tabview_create(screen);
    lv_obj_set_size(tabview, lv_pct(100), lv_pct(100));
    lv_obj_t *tab_main = lv_tabview_add_tab(tabview, "Main");

    for (int i = 0 ; i < MAX_TRAINS ; ++i) {
        lv_obj_t *tab = lv_tabview_add_tab(tabview, "----");
        train_tabs[i] = tab;
        /* Train controls */
        /* Train name */
        lv_obj_t *label = lv_label_create(tab);
        lv_label_set_text(label, "Train name");
        lv_obj_set_align(label, LV_ALIGN_TOP_LEFT);
        lv_obj_set_style_text_font(label, &lv_font_montserrat_20, 0);
        train_names[i] = label;
        /* Train speed */
        lv_obj_t *slider = lv_slider_create(tab);
        lv_obj_set_size(slider, lv_pct(90), 40);
        //lv_slider_bind_value(slider, subject_value);
        lv_obj_align(slider, LV_ALIGN_BOTTOM_MID, 0, -60);
        /* Brake and Rev buttons */
        lv_obj_t *buttonmatrix = lv_buttonmatrix_create(tab);
        lv_obj_set_align(buttonmatrix, LV_ALIGN_BOTTOM_MID);
        lv_obj_set_size(buttonmatrix, lv_pct(90), 40);
        lv_obj_set_style_border_width(buttonmatrix, 0, 0);
        lv_obj_set_style_pad_all(buttonmatrix, 0, 0);
        static const char * buttonmatrix_map_0[] = {"Fwd", "Brake", NULL};
        lv_buttonmatrix_set_map(buttonmatrix, buttonmatrix_map_0);
        /* Stop button */
        lv_obj_t *stopbutton = lv_button_create(tab);
        lv_obj_set_align(stopbutton, LV_ALIGN_TOP_RIGHT);
        lv_obj_t *label_1 = lv_label_create(stopbutton);
        lv_obj_set_align(label_1, LV_ALIGN_CENTER);
        lv_label_set_text(label_1, "Stop");
    }

    bsp_display_unlock();

    logger_init(tab_main);

    /* Print chip information */
    esp_chip_info_t chip_info;
    uint32_t flash_size;
    esp_chip_info(&chip_info);
    logger_printf("This is %s chip with %d CPU core(s), %s%s%s%s\n",
           CONFIG_IDF_TARGET,
           chip_info.cores,
           (chip_info.features & CHIP_FEATURE_WIFI_BGN) ? "WiFi/" : "",
           (chip_info.features & CHIP_FEATURE_BT) ? "BT" : "",
           (chip_info.features & CHIP_FEATURE_BLE) ? "BLE" : "",
           (chip_info.features & CHIP_FEATURE_IEEE802154) ? ", 802.15.4 (Zigbee/Thread)" : "");

    if (esp_flash_get_size(NULL, &flash_size) == ESP_OK) {
        logger_printf("%" PRIu32 "MB %s flash\n", flash_size / (uint32_t)(1024 * 1024),
            (chip_info.features & CHIP_FEATURE_EMB_FLASH) ? "embedded" : "external");
    }
    logger_printf("Free heap size: %" PRIu32 " bytes\n", esp_get_free_heap_size());

    int32_t display_width = lv_disp_get_hor_res(disp);
    int32_t display_height = lv_disp_get_ver_res(disp);
    logger_printf("Display %d x %d\n", display_width, display_height);

    wifi_init();
}

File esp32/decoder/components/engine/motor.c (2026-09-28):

#include "freertos/FreeRTOS.h"
#include "freertos/task.h"
#include "driver/ledc.h"
#include "driver/gpio.h"
#include "string.h"

#include "cv.h"
#include "engine.h"
#include "vm.h"
#include "variables.h"
#include "pins.h"
#include "logger.h"
#include "drv8235.h"

#if CONFIG_BOARD_VERSION <= 2
#define MOTOR_SPEED_MODE        LEDC_LOW_SPEED_MODE
#define MOTOR_CHANNEL1          LEDC_CHANNEL_0
#define MOTOR_CHANNEL2          LEDC_CHANNEL_1
#define MOTOR_TIMER             LEDC_TIMER_0
#define MOTOR_PWM_FREQUENCY     40000
#define MOTOR_PWM_RESOLUTION    LEDC_TIMER_8_BIT
#define MOTOR_VOLTAGE_COUNT     10
#endif
#define MOTOR_PWM_MAX           255

typedef enum EngineState {
    ES_STOPPED = 0,
    ES_STARTING,
    ES_MOVING,
} EngineState;

static bool engine_should_stop;
static EngineState engine_state;
static uint8_t prev_speed;

#if CONFIG_BOARD_VERSION <= 2
static int accel_time;
#endif

static uint8_t engine_get_pwm(uint8_t speed)
{
    uint16_t min = cv_read(CV_VSTART);
    uint8_t max_speed = 255;
    if (vm_get_var(C_SWITCHING)) {
        max_speed = max_speed * cv_read(CV_SWITCHING_TRIM) / 128;
    }
    uint8_t range = min < max_speed ? max_speed - min : min;
    return min + (range * speed) / MOTOR_PWM_MAX;
}

bool engine_can_accelerate(void)
{
    return engine_state == ES_STOPPED
        || (engine_state == ES_MOVING
#if CONFIG_BOARD_VERSION >= 3
            //&& drv8235_get_speed() >= engine_get_pwm(engine_get_speed())
#endif
        );
}

void engine_hw_stop(void)
{
    engine_should_stop = true;
}


static void engine_task(void *args)
{
    while (true) {
#if CONFIG_BOARD_VERSION <= 2
        uint8_t speed = engine_get_speed();
        if (engine_should_stop || speed == 0) {
            engine_should_stop = false;
            ledc_set_duty(MOTOR_SPEED_MODE, MOTOR_CHANNEL1, MOTOR_PWM_MAX);
            ledc_set_duty(MOTOR_SPEED_MODE, MOTOR_CHANNEL2, MOTOR_PWM_MAX);
            ledc_update_duty(MOTOR_SPEED_MODE, MOTOR_CHANNEL1);
            ledc_update_duty(MOTOR_SPEED_MODE, MOTOR_CHANNEL2);
            engine_state = ES_STOPPED;
            prev_speed = 0;
        } else if (engine_state == ES_STOPPED) {
            if (speed > 0) {
                prev_speed = speed;
                bool dir = engine_get_direction();
                uint8_t pwm = MOTOR_PWM_MAX - cv_read(CV_KICK_START);
                uint8_t s1 = MOTOR_PWM_MAX;
                uint8_t s2 = MOTOR_PWM_MAX;
                if (dir) {
                    s2 = pwm;
                } else {
                    s1 = pwm;
                }
                ledc_set_duty(MOTOR_SPEED_MODE, MOTOR_CHANNEL1, s1);
                ledc_set_duty(MOTOR_SPEED_MODE, MOTOR_CHANNEL2, s2);
                ledc_update_duty(MOTOR_SPEED_MODE, MOTOR_CHANNEL1);
                ledc_update_duty(MOTOR_SPEED_MODE, MOTOR_CHANNEL2);
                accel_time = 0;
                engine_state = ES_STARTING;
            }
        } else if (engine_state == ES_STARTING) {
            /* Read motor current */
            ++accel_time;
            if (accel_time >= cv_read(CV_KICK_START_TIME)) {
                engine_state = ES_MOVING;

                /* Update speed */
                uint8_t s1 = MOTOR_PWM_MAX;
                uint8_t s2 = MOTOR_PWM_MAX;
                if (speed) {
                    bool dir = engine_get_direction();
                    // Drive 0 output as PWM
                    uint8_t pwm = MOTOR_PWM_MAX - engine_get_pwm(speed);
                    // FWD 10
                    // REV 01
                    if (dir) {
                        s2 = pwm;
                    } else {
                        s1 = pwm;
                    }
                }
                ledc_set_duty(MOTOR_SPEED_MODE, MOTOR_CHANNEL1, s1);
                ledc_set_duty(MOTOR_SPEED_MODE, MOTOR_CHANNEL2, s2);
                ledc_update_duty(MOTOR_SPEED_MODE, MOTOR_CHANNEL1);
                ledc_update_duty(MOTOR_SPEED_MODE, MOTOR_CHANNEL2);
            }
        } else if (engine_state == ES_MOVING) {
            if (prev_speed != speed) {
                prev_speed = speed;
                /* Update speed */
                uint8_t s1 = MOTOR_PWM_MAX;
                uint8_t s2 = MOTOR_PWM_MAX;
                if (speed) {
                    bool dir = engine_get_direction();
                    // Drive 0 output as PWM
                    uint8_t pwm = MOTOR_PWM_MAX - engine_get_pwm(speed);
                    // FWD 10
                    // REV 01
                    if (dir) {
                        s2 = pwm;
                    } else {
                        s1 = pwm;
                    }
                }
                ledc_set_duty(MOTOR_SPEED_MODE, MOTOR_CHANNEL1, s1);
                ledc_set_duty(MOTOR_SPEED_MODE, MOTOR_CHANNEL2, s2);
                ledc_update_duty(MOTOR_SPEED_MODE, MOTOR_CHANNEL1);
                ledc_update_duty(MOTOR_SPEED_MODE, MOTOR_CHANNEL2);
            }
        }
#else
        uint8_t speed = engine_get_speed();
        if (engine_state == ES_MOVING && (engine_should_stop || speed == 0)) {
            engine_should_stop = false;
            engine_state = ES_STOPPED;
            prev_speed = 0;
            // No need in braking, this may switch the rotation
            // drv8235_set_motor_state(DRV8235_MOTOR_BRAKE);
            drv8235_set_speed(0);
        } else if (prev_speed != speed) {
            prev_speed = speed;
            /* Update speed */
            bool dir = engine_get_direction();
            uint8_t pwm = engine_get_pwm(speed);
            drv8235_set_motor_state(dir ? DRV8235_MOTOR_FORWARD : DRV8235_MOTOR_REVERSE);
            drv8235_set_speed(pwm);
            engine_state = ES_MOVING;
        }
#endif

        /* Wait */
        vTaskDelay(pdMS_TO_TICKS(20));
    }
}

char *engine_get_status(void)
{
// #if CONFIG_BOARD_VERSION >= 3
//     uint8_t speed = drv8235_get_speed();
//     uint8_t fault_status = drv8235_read_reg(DRV8235_REG_FAULT);
//     uint8_t status1 = drv8235_read_reg(DRV8235_REG_REG_STATUS1);
//     uint8_t status2 = drv8235_read_reg(DRV8235_REG_REG_STATUS2);
//     uint8_t status3 = drv8235_read_reg(DRV8235_REG_REG_STATUS3);
//     uint8_t throttle = engine_get_speed();
//     char *s = malloc(256);
//     sprintf(s, "Motor status:\n throttle = %d\n speed = %d\n fault_status = 0x%x\n voltage = %d\n current = %d\n duty = %d\n",
//         throttle, speed, fault_status, status1, status2, status3);
//     return s;
// #else
    return strdup("");
// #endif
}
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

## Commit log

2026-02-25 First version of ESP32 firmware
2026-03-01 Playing prototype
2026-03-06 Implemented sound project upload
    [partitions.csv]
2026-03-06 Changed SPIFFS to LittleFS
    [partitions.csv]
2026-03-07 Decoupled functions and slots
2026-03-08 Added engine control
    [partitions.csv]
2026-05-07 First version of compiler
    [partitions16M.csv, partitions4M.csv]
2026-05-28 Added 32M config
    [partitions32M.csv]
2026-06-04 Updated schematic
    [sounddecoder-esp32-s3-wroom-2.csv, sounddecoder-esp32-s3-wroom-2.kicad_pcb]
2026-06-30 Many changes
    [sounddecoder-esp32-s3-wroom-2.csv]
2026-07-08 Started developing new boards
    [sounddecoder-esp32-s3-wroom-2-ext.kicad_pcb, sounddecoder-esp32-s3-wroom-2-ext.kicad_sch, sounddecoder-esp32-s3-wroom-2-mini.kicad_pcb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]
2026-07-10 Added gerbers
    [sounddecoder-esp32-s3-wroom-2-ext-B_Cu.gbr, sounddecoder-esp32-s3-wroom-2-ext-B_Mask.gbr, sounddecoder-esp32-s3-wroom-2-ext-B_Paste.gbr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]
2026-07-17 Added variable sample rate
2026-07-18 Minor fixes and readme update
    [engine.c]
2026-07-18 Added BR80 project
    [function_keys.cfg, outputs.cfg, slots.cfg]
2026-07-19 Added BR94 project
    [function_keys.cfg, outputs.cfg, slots.cfg]
2026-07-19 Added BigBoy project
    [function_keys.cfg, outputs.cfg, slots.cfg]
2026-07-21 Fixed sound projects
    [function_keys.cfg, slots.cfg]
2026-07-27 Updated mixer and sample player
2026-07-27 renamed esp32 folder
    [partitions16M.csv, partitions32M.csv, partitions4M.csv]
2026-07-29 Added micro board
    [sounddecoder-esp32-s3-wroom-1-B_Cu.gbr, sounddecoder-esp32-s3-wroom-1-B_Mask.gbr, sounddecoder-esp32-s3-wroom-1-B_Paste.gbr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]
2026-07-31 Updated micro decode board
    [sounddecoder-esp32-s3-wroom-2-micro.kicad_pcb, sounddecoder-esp32-s3-wroom-2-micro.kicad_sch]
2026-08-05 Fixed compiler
    [sounddecoder-esp32-s3-wroom-2-micro.kicad_pcb]
2026-08-31 Github action for ESP32 build
2026-09-28 Many updates
    [sounddecoder-esp32-s3-wroom-2-micro.kicad_sch, sounddecoder-esp32-s3-wroom-2-mini.kicad_pcb, sounddecoder-esp32-s3-wroom-2-mini.kicad_sch]
2026-10-02 Refactoring and command station stub
    [partitions.csv, partitions16M.csv, partitions32M.csv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]
